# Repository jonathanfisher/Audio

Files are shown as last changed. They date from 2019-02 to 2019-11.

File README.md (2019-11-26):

# Overview
Now that I work for an audio company, I should really learn more about the various technology that goes into making things sound great. I've decided to spend some time designing my own audio setup (outside of making my own speaker). This project is intended as a learning exercise, not as a product to sell. As such, the commits here may take interesting twists and turns.

# Repository
This repository contains the design files for the PCBs I intend to make. The idea is to eventually design the following stages:

1. [USB](#USB)
2. [DAC](#DAC)
3. [Amplifier](#Amplifier)

I intend to design these as discrete boards that can be chained together. This modular design should allow me to more easily iterate in things I care about. I imagine that I will make mistakes along the way, and will have to re-spin boards.

## USB
This stage is intended to be the interface between a digital audio source (e.g. computer) and the rest of the audio system. USB seemed to be a reasonable medium to use for this.

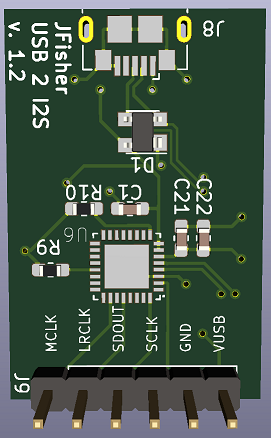
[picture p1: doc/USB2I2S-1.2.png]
USB2I2S PCB Preview


## DAC
This stage is responsible for receiving a stream of digital signals and converting it to an analog output that can be converted to sound by a speaker.

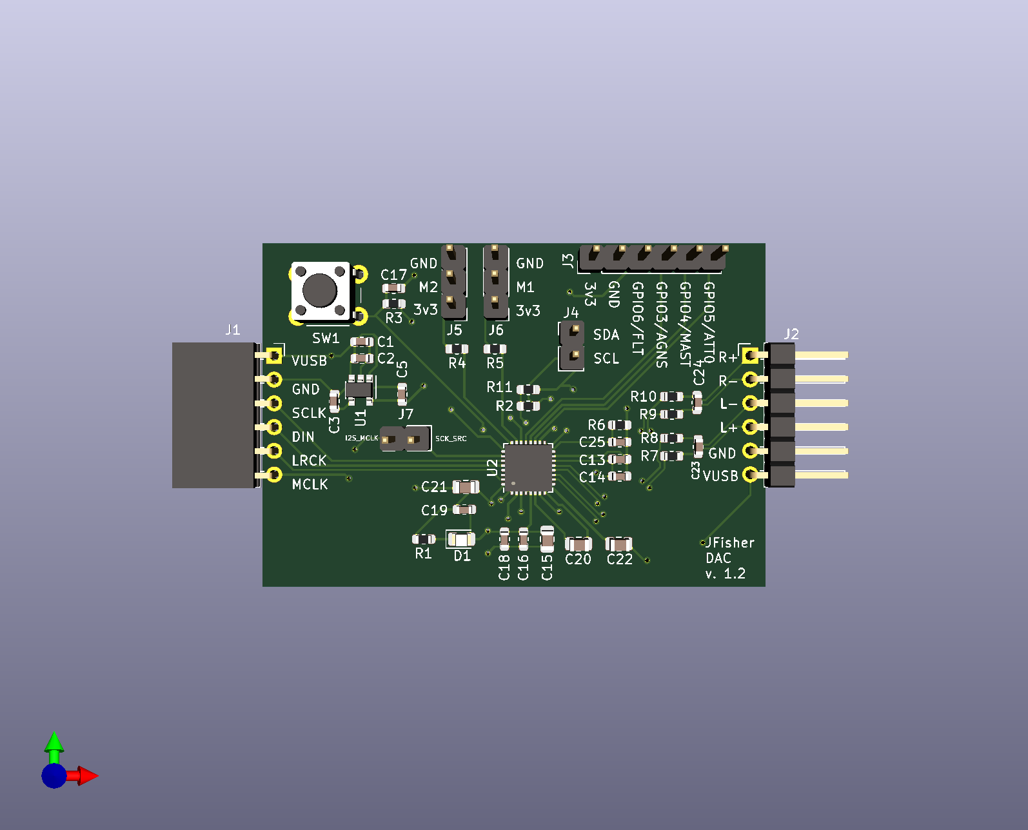
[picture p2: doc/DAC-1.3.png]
DAC PCB Preview


## Amplifier
This stage is responsible for taking the output of the DAC and amplifying it so that the speaker(s) output the desired level of sound.

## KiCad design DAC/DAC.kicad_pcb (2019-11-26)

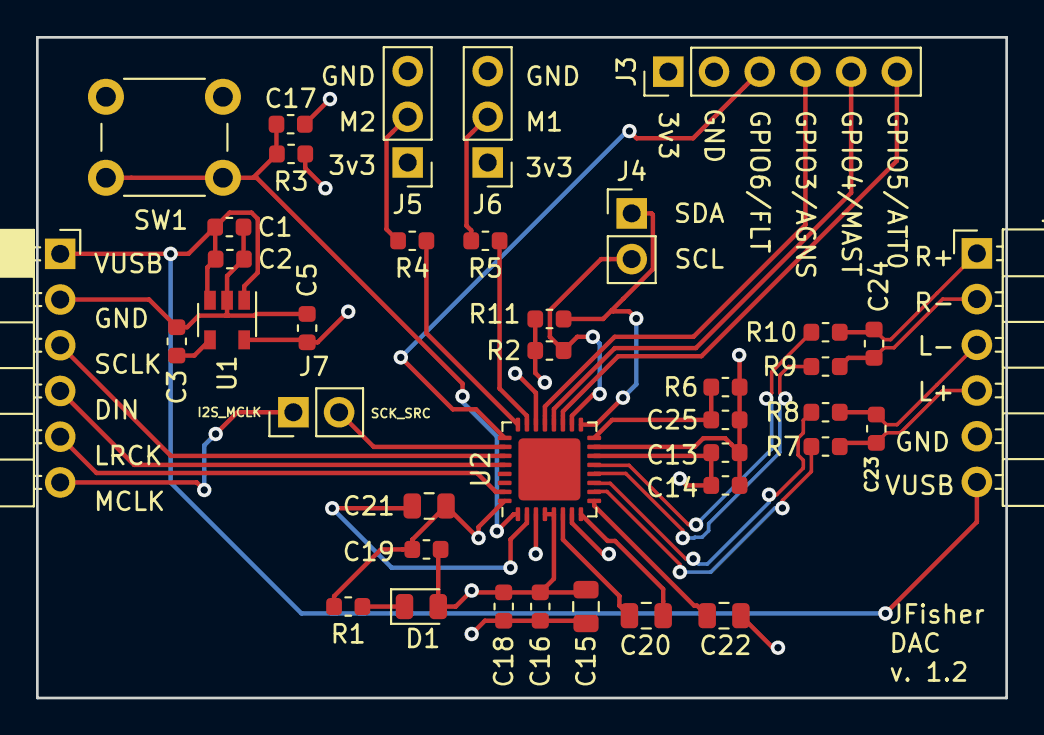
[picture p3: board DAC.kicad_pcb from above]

Board: 4 copper layers, 53.8 x 36.7 mm, 39 parts (0 on the bottom side), 34 nets.

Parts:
C1, C13, C18: 10uF; C_0603_1608Metric
C2, C14, C16, C17, C19: 0.1uF; C_0603_1608Metric
C3: 0.01uF; C_0603_1608Metric
C5: 1uF; C_0603_1608Metric
C15, C20, C22: 2.2uF; C_0805_2012Metric
C21: 0.1uF; C_0805_2012Metric
C23, C24: 1000pF; C_0603_1608Metric
C25: 1.0uF; C_0603_1608Metric
D1: LED_3v3; LED_0805_2012Metric
J1: Conn_01x06; PinSocket_1x06_P2.54mm_Horizontal
J2: Conn_01x06; PinHeader_1x06_P2.54mm_Horizontal
J3: Conn_01x06_Male; PinHeader_1x06_P2.54mm_Vertical
J4, J7: Conn_01x02; PinHeader_1x02_P2.54mm_Vertical
J5, J6: Conn_01x03_Male; PinHeader_1x03_P2.54mm_Vertical
R1: 360; R_0603_1608Metric
R2, R11: 4.7k; R_0603_1608Metric
R3: 10k; R_0603_1608Metric
R4, R5: 4.99k; R_0603_1608Metric
R6: 0; R_0603_1608Metric
R7, R8, R9, R10: 499; R_0603_1608Metric
SW1: SW_Push; SW_PUSH_6mm
U1: TPS73633DBV; SOT-23-5
U2: PCM5242RHB; Texas_S-PVQFN-N32_EP3.45x3.45mm

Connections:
+3V3: C5.1, C13.1, C14.1, C15.1, C16.1, C18.1, C19.1, D1.2, J3.1, J5.1, J6.1, R2.1, R3.2, R11.1, U1.5, U2.4, U2.5, U2.14
DACL+: C23.1, J2.4, R7.1
DACL-: C23.2, J2.3, R8.1
DACR+: C24.2, J2.1, R10.1
DACR-: C24.1, J2.2, R9.1
GND: C1.2, C2.2, C3.2, C5.2, C13.2, C14.2, C15.2, C16.2, C17.2, C18.2, C19.2, C21.2, C22.2, C25.2, J1.2, J2.5, J3.2, J5.3, J6.3, R1.2, R6.1, SW1.1, U1.2, U2.3, U2.7, U2.15, U2.22, U2.32
GPIO3_AGNS: J3.4, U2.21
GPIO4_MAST: J3.5, U2.20
GPIO5_ATT0: J3.6, U2.19
GPIO6_FLT: J3.3, U2.25
I2S_DIN: J1.4, U2.28
I2S_LRCK: J1.5, U2.31
I2S_MCLK: J1.6, J7.1
I2S_SCK_SRC: J7.2, U2.26
I2S_SCLK: J1.3, U2.27
MODE1: R5.1, U2.23
MODE2: R4.1, U2.24
unnamed: C3.1, U1.4
unnamed: C17.1, R3.1, SW1.2, U2.1
unnamed: C20.1, U2.6
unnamed: C20.2, U2.8
unnamed: C21.1, U2.2
unnamed: C22.1, U2.9
unnamed: C25.1, R6.2, U2.16
unnamed: D1.1, R1.1
unnamed: J5.2, R4.2
unnamed: J6.2, R5.2
OUTL_N: R8.2, U2.11
OUTL_P: R7.2, U2.10
OUTR_N: R9.2, U2.12
OUTR_P: R10.2, U2.13
SCL_MC_ATT1: J4.2, R2.2, U2.18
SDA_MOSI_ATT2: J4.1, R11.2, U2.17
VUSB: C1.1, C2.1, J1.1, J2.6, U1.1, U1.3

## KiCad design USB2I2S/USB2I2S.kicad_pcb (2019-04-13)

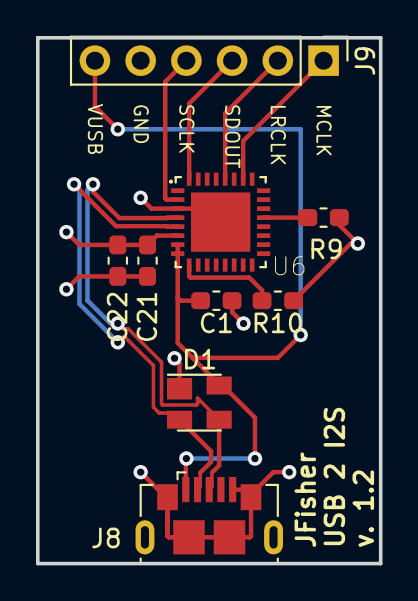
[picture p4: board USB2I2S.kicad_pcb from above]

Board: 4 copper layers, 19.1 x 29.2 mm, 9 parts (0 on the bottom side), 11 nets.

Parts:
C1, C21: 1uF; C_0603_1608Metric_Pad1.05x0.95mm_HandSolder
C22: 0.1uF; C_0603_1608Metric_Pad1.05x0.95mm_HandSolder
D1: SP0503BAHT; SOT-143
J8: USB_B_Micro; USB_Micro-B_GCT_USB3076-30-A
J9: Conn_01x06_Male; PinHeader_1x06_P2.54mm_Vertical
R9, R10: 4.7K; R_0603_1608Metric_Pad1.05x0.95mm_HandSolder
U6: CP2615-A01-GM; QFN50P500X500X90-33N

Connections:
GND: C1.2, C21.2, C22.2, D1.1, J8.5, J8.6, J9.5, U6.3, U6.33
I2S_LRCLK: J9.2, U6.28
I2S_MCLK: J9.1, U6.26
I2S_SCLK: J9.4, U6.2
I2S_SDOUT: J9.3, U6.32
unnamed: R9.2, U6.21
unnamed: R10.2, U6.9
USB_DN: D1.2, J8.2, U6.5
USB_DP: D1.3, J8.3, U6.4
VBUS_IN: C1.1, D1.4, J8.1, J9.6, U6.7, U6.8
VCC: C21.1, C22.1, R9.1, R10.1, U6.6

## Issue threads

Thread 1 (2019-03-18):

Improve routing on the USB -> I2S PCB

jonathanfisher, 2019-03-18:
The routing of the USB -> I2S board leaves a lot to be desired (e.g. move decoupling caps closer to the IC, route USB data lines according to the USB recommendations). This will probably require moving to a 4-layer PCB. This should be done for the next spin of the board.

jonathanfisher, 2019-03-26:
Resolved in commit `5fc1e62841ba576ad97ec8ca261a6b44300cc573`, which changes the PCB to a 4-layer board, removes some extra headers and has better routing of the differential USB signal.

Closed 2019-03-26.

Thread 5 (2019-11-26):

GPIO silk screen labels are out of order

jonathanfisher, 2019-11-26:
Looking at the board with the inputs to the left and the outputs to the right, the labels current are in this order:

`+3v3 | GND | GPIO3/AGNS | GPIO4/MAST | GPIO5/ATT0 | GPIO6/FLT`

However, that does not reflect the signals correctly. The correct ordering is:
`+3v3 | GND | GPIO6/FLT | GPIO3/AGNS | GPIO4/MAST | GPIO5/ATT0`

jonathanfisher, 2019-11-26:
Fixed by 971e676db3e87bd76b2967b98e3511d9d42aa7ec.

Closed 2019-11-26.

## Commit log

2019-02-13 Initial commit with basic files for Audio DAC
    [AudioDAC.kicad_pcb, AudioDAC.sch, DAC.sch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]
2019-02-15 Add schematic for the USB -> I2S stage
    [UsbToI2s.sch]
2019-02-15 Bring in project with multi-page design
    [AudioDAC.sch, DAC.sch, IO.sch]
2019-02-19 Add components for creating 3v3 for the DAC power rails
    [AudioDAC.sch, DAC.sch, IO.sch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]
2019-03-07 Schematic and board file for USB2I2S dongle
    [USB2I2S.kicad_pcb, USB2I2S.sch]
2019-03-11 Start designing the DAC stage
    [DAC.kicad_pcb, DAC.sch, _saved_DAC.sch]
2019-03-17 Remove old and unused scratch files
    [AudioDAC.kicad_pcb, AudioDAC.sch, DAC.sch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]
2019-03-18 Add sheet for the actual DAC part
    [DigitalToAnalog.sch]
2019-03-18 Add sheet for power conversion (USB -> 3v3 for now)
    [Power.sch]
2019-03-18 Add Sheets for the I/O for this board. Still WIP on output
    [Input.sch, Output.sch]
2019-03-18 Bring changes together in outmost sheet. This should just pull together the various subsheets
    [DAC.sch, _saved_DAC.sch]
2019-03-18 Remove unused I/V stage on output of DAC
    [Output.sch]
2019-03-19 Add new sheet for amplifier (post i-v stage)
    I'm not sure if I'll stick with this here; my thinking is that it makes
    sense to keep the post I-V stage amplifier on the same PCB as the DAC to
    minimize noise on the amplifier input. I imagine that PCB interconnects
    would cause a fairly significant amount of noise, so I'd like to avoid
    that.
    [Amplifier.sch, DAC.sch, DigitalToAnalog.sch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]
2019-03-21 Adding support for headphone amp (WIP)
    [Amplifier.sch, DAC.sch, DigitalToAnalog.sch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]
2019-03-22 Started layout of the DAC board
    [Amplifier.sch, AmplifierPower.sch, DAC.kicad_pcb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]
2019-03-25 Update USB2I2S board to fix routing issue
    - Fixed issue where VCC was connected to VUSB
    - Converted PCB to 4-layer board with Vcc and GND planes
    - Removed headers for pins that I'm not expecting to use
    - Re-layed out the PCB.
    [USB2I2S.kicad_pcb, USB2I2S.sch]
2019-03-25 Update KiCad and minor adjustments (cosmetic)
    Rotated the decoupling caps on Vcc to ensure that the blind vias were
    away from the differential USB signal traces.
    [USB2I2S.kicad_pcb]
2019-03-26 Remove extraneous directory (DAC/DAC/ -> DAC/)
    [Amplifier.sch, DAC.kicad_pcb, DAC.sch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]
2019-03-26 Added first pass at routing the DAC PCB
    [DAC.kicad_pcb, DAC.sch, DigitalToAnalog.sch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]
2019-03-26 Update routing of DAC board
    - Route differential outputs with matching lengths
    - Add silkscreen labels for inputs and outputs
    [DAC.kicad_pcb]
2019-03-26 Updated routing information & silk screens
    - Update pin names of differential outputs of PCM5242
    - Better alignment of silkscreen component labels
    [DAC.kicad_pcb, DigitalToAnalog.sch]
2019-03-27 Convert blind vias to through vias
    [USB2I2S.kicad_pcb]
2019-04-01 Convert blind vias to through and minor silkscreen changes
    This is the version released to be made
    [USB2I2S.kicad_pcb]
2019-04-01 Convert blind vias to through and update DAC layout
    This will constitute the first spin of the DAC board.
    [DAC.kicad_pcb]
2019-04-13 Fixed the VUSB <-> REGIN error causing board not to create Vcc.
    [USB2I2S.kicad_pcb, USB2I2S.sch]
2019-09-29 Work around DAC incompatibility with I2S clock (#4)
    * Update DAC to expose config pins and to use larger components
    * Ignore some more cache & backup files
    * Update PCB placement
    * Add headers for MCLK/SCLK signal to allow for clock workaround
    This helps to address the issue called out in the datasheet: https://e2e.ti.com/support/audio/f/6/p/804836/2980033#2980033, allowing the DAC to receive the MCLK input and create a usable SCLK input from it.
    [DAC.kicad_pcb, DAC.sch, DigitalToAnalog.sch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]
2019-09-29 Update README with some renderings of PCBs
2019-11-26 Fix GPIO labeling on DAC silk screen (Issue #5)
    The GPIO labels were incorrectly placed and thus wrong.
    [DAC.kicad_pcb]
